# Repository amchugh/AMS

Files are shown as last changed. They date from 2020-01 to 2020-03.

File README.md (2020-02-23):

# AMS - Audio Monitoring System

This system utilizes multiple hardware nodes to listen for sound levels and display an aggregate view on a 
'server' instance.  

Nodes are comprised of:
 * Adafruit Feather Huzzah with ESP8266 - https://www.adafruit.com/product/2821
 * Featherwing OLED displays - https://www.adafruit.com/product/2900
 * Electret microphones - https://www.adafruit.com/product/1063

Server instance is:
 * Adafruit Feather Huzzah with ESP8266 - https://www.adafruit.com/product/2821
 * Featherwing touch screen display - https://www.adafruit.com/product/3315

The goal for fidelity of information being transferred is:
- ~100 samples sent from the listening nodes to the server 
- <=5% drop rate at 30ft through a wall
- Number of packets per second and therefore their size will be determined by packet processing speed on the server. 

## Diagnosing a server instance

It is possible to run the server instance in a 'data gathering' mode.  Compile
and flash the ServerFirmware with DEBUG_PRINT_SHOW_DATA_DETAILS defined at the 
top of the file.  Use the arduino software's serial monitor (or any other
program to see the serial output) making sure that the baud rate matches the
configuration in the server firmware (currently 57600 baud).  

Connect a client or run:

```
python sendExampleSequence.py 1 1 
```

from the commnad line.  The output lines look like this:

```
...
handleUDPPacket; currentTime: 409759, IP: 192.168.4.2, ID: 1, stationIndex: 0, packetNumber: 132, dataIndex: 3, data: 47
handleUDPPacket; currentTime: 409844, IP: 192.168.4.2, ID: 1, stationIndex: 0, packetNumber: 134, dataIndex: 0, data: 93
...
```

The IP, ID and stationIndex are all used to distinguish one listening station
from another.  IP will likely be unique and sufficient.  A single packet can
contain many data values and dataIndex is the index of the data value (the
last component in the log line) within the packet.

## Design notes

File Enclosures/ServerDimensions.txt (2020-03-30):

Dimensions for the Adafruit 2.4inch TFT display for the Featherwing

--

64.77 Wide  (midpoint: 32.385)
52.578 Tall (midpoint: 26.289)

Viewing window 50.75mm x 38.5mm 
It is 7.01 mm from each side
It is 7.04 mm from the top to bottom

--

2.54mm diameter of circles.
The center is offset 2.54mm from the side

4mm from each end.

--

Good thickness/heights are as follows.
For the front panel 2mm thick for the outer wall.
The Post should be 4mm beyond that (6mm high).
The little post should be 3mm beyond that (9mm).

A 2mm round over in the viewing area for the screen.
(Too much and you get some ugly flatness.)

Make the outer wall be 6mm tall. 

--

Assume using 3mm screws to attach the top to the base. 

--

Captive nut for M3 screw is:
  - 5.45mm across the flats 
  - 6.06 across the corners 
  - 3.16 for each side
  - 2.24mm for its depth 

--

Power button is 6.2mm wide.
12.25mm at tallest point.
10.25 at least tallest point.

Opening for the USB cord is:
  12mm wide
  10mm tall
   3mm deep

--

60 degree tilt.
26mm height for the base.

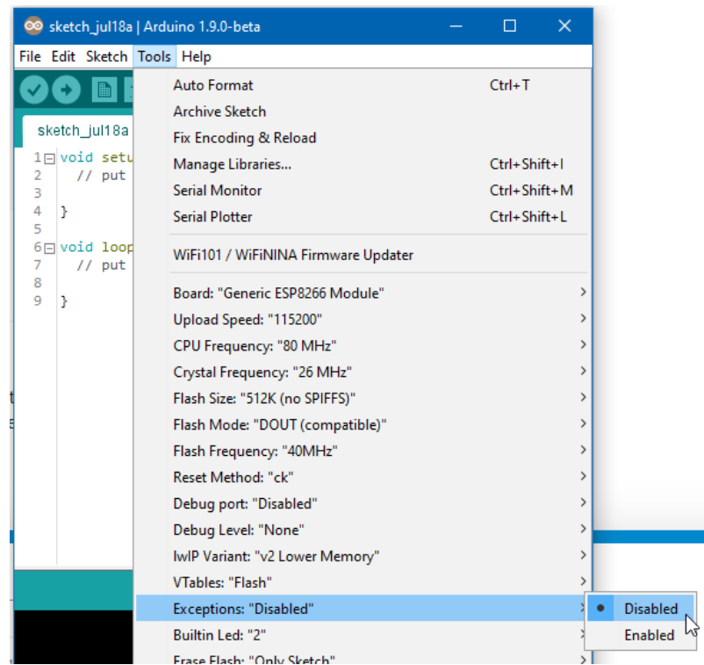
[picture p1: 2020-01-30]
images/MustEnableExceptions.PNG

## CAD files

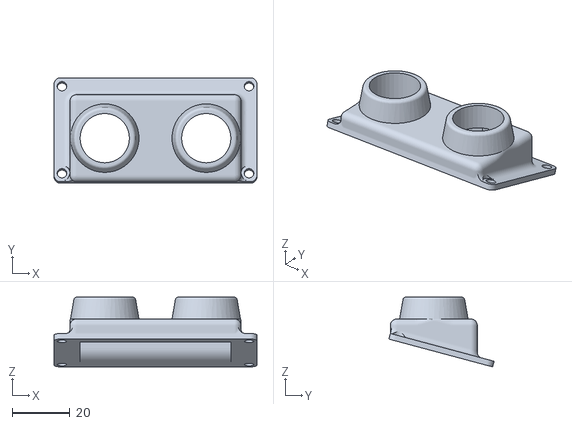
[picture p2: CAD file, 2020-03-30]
Enclosures/us_range.STL
70.0 x 36.3 x 24.1

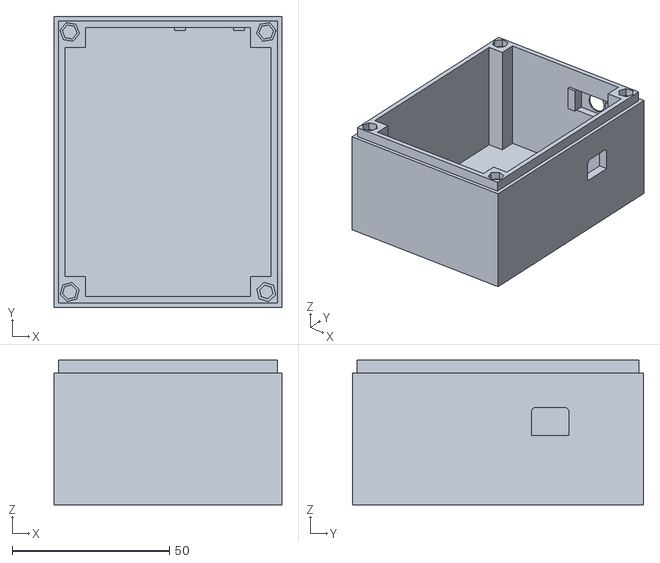
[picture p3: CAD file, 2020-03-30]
Enclosures/S-Bottom-V12.stl
72.6 x 92.8 x 46.0

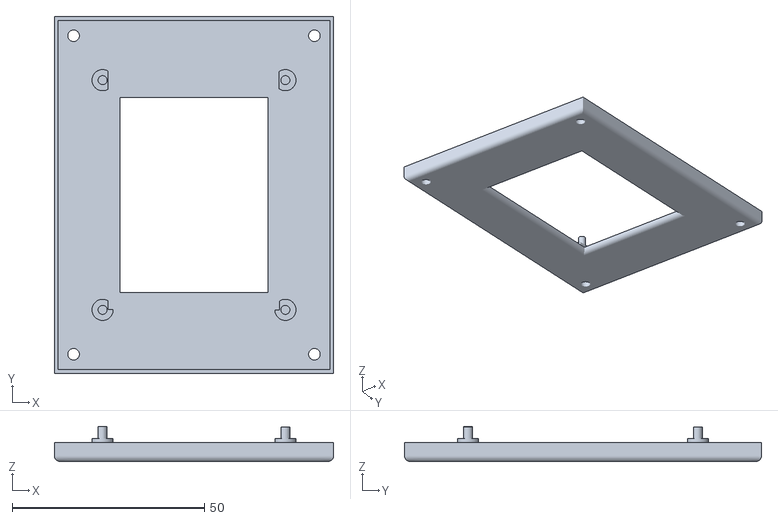
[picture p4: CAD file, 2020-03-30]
Enclosures/S-Top-V12.stl
72.6 x 92.8 x 9.10

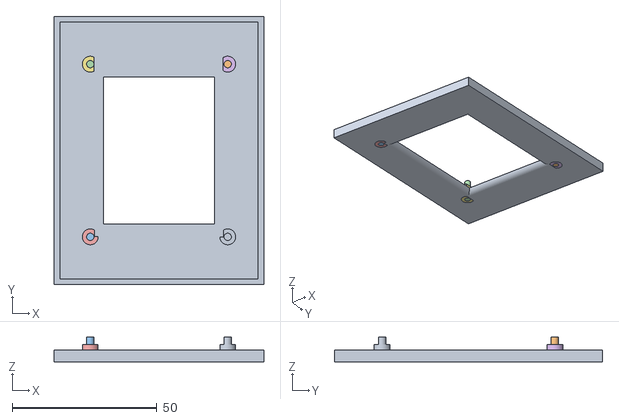
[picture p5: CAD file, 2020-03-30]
Enclosures/S-v2.stl
72.6 x 92.8 x 8.50

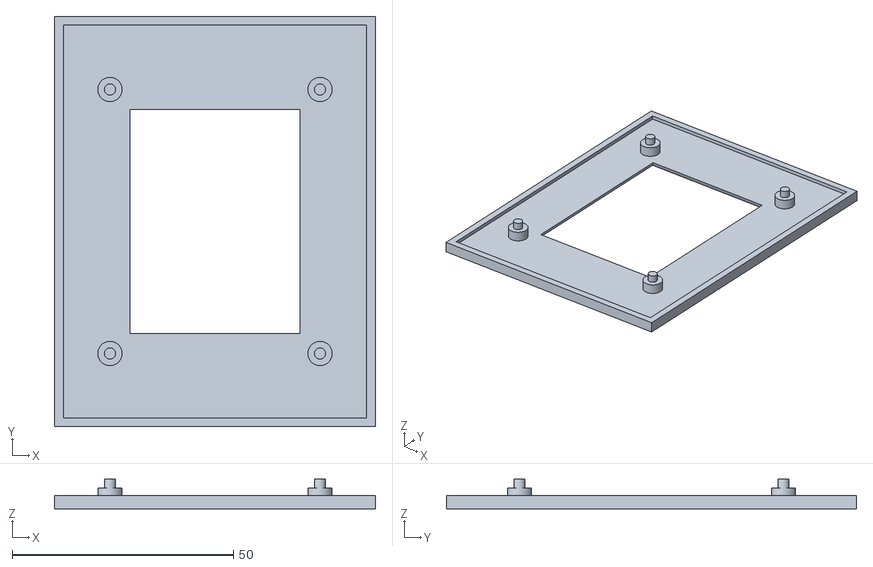
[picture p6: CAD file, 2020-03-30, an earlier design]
Enclosures/S-V1.stl
72.6 x 92.8 x 6.75

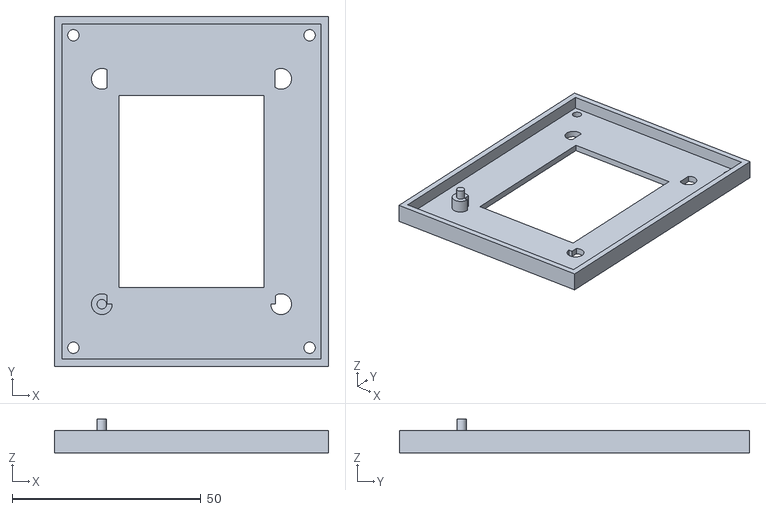
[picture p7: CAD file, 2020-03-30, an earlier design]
Enclosures/S-Top-v3.stl
72.6 x 92.8 x 9.00

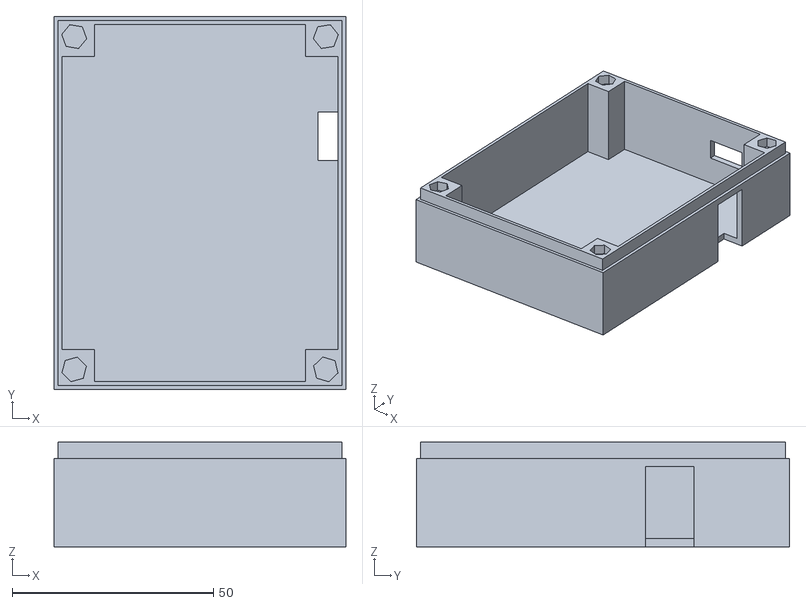
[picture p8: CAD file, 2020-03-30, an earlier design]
Enclosures/S-bottom-v3.stl
72.6 x 92.8 x 26.0

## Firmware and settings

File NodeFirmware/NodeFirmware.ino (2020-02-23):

// This is the listener 'node' code and is intended to be run on an Adafruit
// Feather Huzzah (https://www.adafruit.com/product/2821) coupled with a
// 128x32 OLED FeatherWing display
// (https://learn.adafruit.com/adafruit-oled-featherwing?view=all)
// and an electret microphone (https://www.adafruit.com/product/1063).

// When uploading the code ensure that 
//  Board: Adafruit Feather Huzzah ESP8266
//  Upload speed: 115200
//  CPU: 80 Mhz

// Needed Libraries:
// Adafruit GFX Library - https://github.com/adafruit/Adafruit-GFX-Library
// WiFiManager for ESP8266 by tzapu - https://github.com/tzapu/WiFiManager
// Adafruit_SSD1306 - https://github.com/adafruit/Adafruit_SSD1306

#include <Wire.h>
#include <Adafruit_GFX.h>
#include <Adafruit_SSD1306.h>
#include <ESP8266WiFi.h>
#include <WiFiUdp.h>

// Define server constants
const char *ssidtarget = "AMS-server";

// Location of the server
IPAddress destip(192,168,4,1);
unsigned int serverUDPPort = 8888;

// Setup our listen port
unsigned int localUDPPort = 8888;

// Define the display
Adafruit_SSD1306 display = Adafruit_SSD1306(128, 32, &Wire);

// Define the Udp service!
WiFiUDP Udp;

// Define the button pins
#define A_BUTTON 0
#define B_BUTTON 16
#define C_BUTTON 2

// Define buffers for UDP incoming and outgoing data
char ipacket[UDP_TX_PACKET_MAX_SIZE];
char opacket[UDP_TX_PACKET_MAX_SIZE];

bool doSend = false;
bool wasPressed = false;
uint32_t packetNumber = 0;
uint8_t stationId;
float accumulationSamplesSent = 0;
uint32_t accumulationStartTime = 0;

// The listener node collects data 'samples' and packages them together
// into a 'packet' of data that is communicated with the server.   A 
// single 'sample' is actually many readings of the microphone where we
// are looking in the distance between the high and low value.  
typedef struct {
  uint16_t minValue;
  uint16_t maxValue;
  uint16_t sampleCount;
} Sample;

void setup() {
  Serial.begin(57600);
  // Set the button pinmodes
  pinMode(A_BUTTON, INPUT_PULLUP);
  pinMode(B_BUTTON, INPUT_PULLUP);
  pinMode(C_BUTTON, INPUT_PULLUP);
  // Define the pinmode for the audio sensor
  pinMode(A0, INPUT);

  // Init the display
  display.begin(SSD1306_SWITCHCAPVCC, 0x3c);

  // Try to connect to the server
  WiFi.persistent(false);
  WiFi.mode(WIFI_STA);
  WiFi.begin(ssidtarget, NULL);

  // Print the "searching" message
  int numDots = 0;
  while (WiFi.status() != WL_CONNECTED) {
    if (numDots == 0) { 
      printSearching();
    }
    delay(50);
    Serial.print(".");
    display.print(".");
    display.display();
    numDots++;
    if (numDots == 32) { 
      numDots = 0;
    }
  }
  Serial.println();
  Serial.println("Connected!");

  stationId = WiFi.localIP()[3];

  // Set up the UDP service
  Udp.begin(localUDPPort);

  // Print the ready message
  printConnected();
}

// ------------------------------
// Printing section

// Print a message saying that we are connected to WiFi
void printConnected() {
  display.clearDisplay();
  display.setTextSize(1);
  display.setTextColor(SSD1306_WHITE);
  display.setCursor(0,0);
  display.print("Station ");
  display.print(stationId);
  display.println(" Connected!");
  display.println();
  display.println("Press A to begin");
  display.display();
}

// Print a message to the display that we are searching
void printSearching() {
  display.clearDisplay();
  display.setTextSize(1);
  display.setTextColor(SSD1306_WHITE);
  display.setCursor(0,0);
  display.println("Connecting");
  display.display();
}

void printSendingMessage() {
  display.clearDisplay();
  display.setTextSize(1);
  display.setTextColor(SSD1306_WHITE);
  display.setCursor(0,0);
  display.println("Sending Data");

  display.setCursor(0,16);
  display.println("Packets: ");

  // SPS is 'samples per second'.  This gives us a sense of how many 
  // noise readings per second we are sending.  
  display.setCursor(0,24);
  display.println("SPS: ");

  display.display();
}

void printStandbyMessage(int packetCount) {
  display.clearDisplay();
  display.setTextSize(1);
  display.setTextColor(SSD1306_WHITE);
  display.setCursor(0,0);
  display.println("Standing By");
  display.println("Press A to begin");
  display.print("Packets Sent: ");
  display.println(packetCount);
  display.display();
}

// ------------------------------

void handleUDPPacket() {
 int packetSize = Udp.parsePacket();
 if (packetSize) {
    Serial.printf("Received packet of size %d from %s:%d\n    (to %s:%d, free heap = %d B)\n",
                  packetSize,
                  Udp.remoteIP().toString().c_str(), Udp.remotePort(),
                  Udp.destinationIP().toString().c_str(), Udp.localPort(),
                  ESP.getFreeHeap());

    // read the packet into packetBufffer
    int n = Udp.read(ipacket, UDP_TX_PACKET_MAX_SIZE);
    ipacket[n] = 0;
    Serial.println("Contents:");
    Serial.println(ipacket);
  }
}

// ---------------------------
// Collecting and Sending Data
//
// For details on the packet layout for both the header data and the 
// samples themselves see PacketDecoder.h.  

// The number of bytes allocated for the header data.  
#define HEADER_SIZE_BYTES 2

// How many pieces of sensor information should be in each packet?
// MUST BE A MULTIPLE OF 4 TO ENSURE PROPER ENCODING
const uint16_t PACKETSAMPLESIZE = 16;

// The current index for a data sample within the larger packet. 
uint16_t currentSample = 0;

// Sets the information in the header of the packet
void setupPacket() {
  // Clear out the entire packet so the bit manipulations work correctly.
  memset(opacket, 0, UDP_TX_PACKET_MAX_SIZE);

  currentSample = 0;
  opacket[0] = stationId;
  opacket[1] = packetNumber % (256);
}

// In testing our hardware we can get about 50 samples in a 5 millisecond
// period.  Shorter durations here will make the unit more responsive.
// Keep in mind that we collect many samples before sending them to the
// server.
#define SAMPLE_DURATION_MS 10
Sample getDataSample() { 
  Sample result;

  result.maxValue = 0;
  result.minValue = 1025;
  result.sampleCount = 0;

  unsigned long startMillis = millis();  

  while (millis() - startMillis < SAMPLE_DURATION_MS) {
    uint16_t v = analogRead(A0);
    if (v > result.maxValue) {
      result.maxValue = v; 
    } 
    if (v < result.minValue) {
      result.minValue = v; 
    }
    result.sampleCount++;
  }
  return result;
}

uint8_t getPacketSize() {
  int groupNumber = currentSample / 4;
  return HEADER_SIZE_BYTES + (groupNumber) * 5;
}

// This method will get the data from the sensor and add it to the out packet
void collectData() {

  Sample s = getDataSample();

  // The raw data values are not useful but the difference in the minimum and
  // maximum value gives us a sense of volume level that has occured during
  // the time we have sampled the waveform. 
  uint16_t d = s.maxValue - s.minValue;

#ifdef DEBUG
  Serial.printf("collectData; min: %d, max: %d, count: %d, v: %d\n", 
    s.minValue, s.maxValue, s.sampleCount, d);
#endif

  // The 10 bit value appearing in d is placed in the outgoing packet. 
  // Current encoding puts the first 8 bits in the next available slot
  // then the last 2 bits in with a group of other high order bits.
  int group_number   = currentSample / 4;
  int s_group_pos    = currentSample % 4;
  int group_byte_loc = HEADER_SIZE_BYTES + ((group_number+1) * 5) - 1;   // -1 for index 0
  int s_byte_loc     = HEADER_SIZE_BYTES + (group_number*5 + s_group_pos); 

  opacket[s_byte_loc]     = d & 0xFF;
  opacket[group_byte_loc] = opacket[group_byte_loc] | ((d >> 8) << 2*s_group_pos);

  // Increment counters
  currentSample++;
  accumulationSamplesSent++;
}

// Sends whatever is in the opacket and resets counters
void sendPacket() {
  Udp.beginPacket(destip, serverUDPPort);
  Udp.write(opacket, getPacketSize());
  Udp.endPacket();
}

void loop() {
  if (!digitalRead(A_BUTTON)) {
    // Toggle the behavior when the A button is pressed back and forth between
    // our two modes.
    if (!wasPressed) {
      if (doSend) {
        doSend = false;
        printStandbyMessage(packetNumber);
      } else {
        accumulationStartTime = millis();
        accumulationSamplesSent = 0;
        doSend = true;
        printSendingMessage();
      }
      wasPressed = true;
    }
  } else {
    wasPressed = false;
  }

  if (doSend) {
    // Get ready for the next packet to be sent. 
    setupPacket();

    // We use a tight while loop here so that we accumulate and send an 
    // entire packet of data with semi-strict timing requirements.  
    while (currentSample < PACKETSAMPLESIZE) {
      collectData();
    } 
    sendPacket();
    packetNumber++;
  
    display.fillRect(53,16,70,8, SSD1306_BLACK);
    display.setTextColor(SSD1306_WHITE);
    display.setCursor(53,16);
    display.print(packetNumber);

    unsigned long int elapsedTime = millis() - accumulationStartTime;
    if (elapsedTime > 3000) { 
      // Every so often update the sps - Samples Per Second.
      display.fillRect(53,24,70,8, SSD1306_BLACK);
      display.setTextColor(SSD1306_WHITE);
      display.setCursor(53,24);
      display.print( (float) 
        ( (accumulationSamplesSent) / ( (float)elapsedTime / 1000) ) 
      );

      accumulationStartTime = millis();
      accumulationSamplesSent = 0;
    }
    display.display();
  }

  // See if there are any UDP packets for us to process.
  handleUDPPacket();
}

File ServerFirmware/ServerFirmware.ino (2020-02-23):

// Libraries necessary for this firmware:
//   Adafruit GFX Library - https://github.com/adafruit/Adafruit-GFX-Library
//   Adafruit ILI9341 Library - https://github.com/adafruit/Adafruit_ILI9341
//   Adafruit STMPE610 - https://github.com/adafruit/Adafruit_STMPE610
//   Mini Grafx by Daniel Eichhorn - https://github.com/ThingPulse/minigrafx
//   WiFiManager for ESP8266 by tzapu - https://github.com/tzapu/WiFiManager

// 
// This is the 'server' code and is intended to be run on an Adafruit Feather 
// Huzzah (https://www.adafruit.com/product/2821) coupled with a TFT 
// Featherwing 2.4" touchscreen (https://www.adafruit.com/product/3315).  
// 
// When uploading the code ensure that 
//  Board: Adafruit Feather Huzzah ESP8266
//  Upload speed: 115200
//  CPU: 80 Mhz


#include <SPI.h>
#include <Adafruit_GFX.h>
#include <Adafruit_ILI9341.h>
#include <Adafruit_STMPE610.h>
#include <ESP8266WiFi.h>
#include <ESP8266WebServer.h>
#include <WiFiUdp.h>
#include "Station.h"
#include "PacketDecoder.h"
#include "GfxGraphing.h"
#include "SmartTextField.h"

// Defines used for the TFT display
#define STMPE_CS 16
#define TFT_CS   0
#define TFT_DC   15
#define SD_CS    2


// DEBUG_PRINT* defines will output via the serial interface debug information 
// #define DEBUG_PRINT
// #define DEBUG_PRINT_SHOW_DATA_DETAILS

// Keeping things simple with a maximum number of stations that are tracked with this instance.
#define MAX_NUMBER_STATIONS 4
Station stations[MAX_NUMBER_STATIONS];

const char *ssid = "AMS-server";
unsigned int localUDPPort = 8888;

// Graphical elements
SegmentedBarGraph *g[MAX_NUMBER_STATIONS];
SmartTextField<int> *connTextField;
SmartTextField<int> *packetsTextField;

// Allocate buffers for sending and receiving UDP data.
// The maximum UDP packet size is defined in https://github.com/esp8266/Arduino/blob/master/libraries/ESP8266WiFi/src/WiFiUdp.h
// and, as of 1/22/2020, is 8k.  
byte incomingPacket[UDP_TX_PACKET_MAX_SIZE+1]; 

// An HTTP server exists for diagnostic and debugging purposes
ESP8266WebServer server(80);

WiFiUDP Udp;
Adafruit_ILI9341 tft = Adafruit_ILI9341(TFT_CS, TFT_DC);
Adafruit_STMPE610 ts = Adafruit_STMPE610(STMPE_CS);

// The number of milliseconds to delay between each frame render.
#define RENDER_FRAME_DELAY_MS 30
uint32_t lastGraphRenderTime = 0;

void setup() {
  Serial.begin(57600);

  delay(10);
  Serial.println("Server firmware started.");
  tft.begin();
  tft.setRotation(1);

  // The Wifi library for the ESP8266 tries to be too smart for its own
  // good.  At one point I had flashed another program to the server which 
  // connected to the AP.  This was saved in flash and then it would always
  // even when softAP mode was enabled, try to connect to it.  When it 
  // didn't exist then the AP SSID would go in and out and I was only able
  // to receive 1 of every 4 packets.  Finally tracked it down.  The below
  // makes it explicit that I don't want the 'smarts' found within the 
  // library.
  WiFi.setAutoConnect(false);
  WiFi.persistent(false);
  WiFi.mode(WIFI_AP);

  // Create a soft access point for the stations to connect to.
  bool result = WiFi.softAP(
    ssid,
    NULL,  /* Password - null means none */
    7,     /* Channel number 1 - 13 available.  Default is 1. */
           /* Use a program like WiFi Analyzer to find best channel */
    false, /* Is the SSID hidden? */ 
    5      /* Maximum number of connections */
  ); 
  if (!result) { 
    Serial.println("Unable to setup the softAP mode!");
    tft.fillScreen(ILI9341_BLACK);
    tft.setCursor(0, 0); tft.setTextColor(ILI9341_RED); tft.setTextSize(2);
    tft.println("Error creating soft AP");
    delay(5000);
    while(1) {}
  }

  displayWelcome();

  // Start listening for packets on the UDP port.
  Udp.begin(localUDPPort);
    
  server.on("/", handleRoot);
  server.begin();
  Serial.println("HTTP server started");

#define XOFFSET 40 
#define WIDTH 320

#define SEGMENTSIZE ((WIDTH - (XOFFSET*2)) / MAX_NUMBER_STATIONS)

  //  0     40    100    160    220    280     320
  //  |     |      +      +      +       |      |

  for (int i=0; i<MAX_NUMBER_STATIONS; i++) { 
    initializeStation(stations[i]);
    g[i] = new SegmentedBarGraph( tft, XOFFSET + (SEGMENTSIZE * i) + ((SEGMENTSIZE - 2*24)/2), 32, 24, 152 );
    g[i]->setBackgroundColor(ILI9341_BLACK);
    g[i]->setBorderColor(ILI9341_WHITE);
    g[i]->setMinAndMaxYAxisValues(0, 1024);
    g[i]->setSegmentGroupColors(ILI9341_GREEN, ILI9341_YELLOW, ILI9341_RED);
    g[i]->startGraphing();
  }
  for (int i=0; i<(MAX_NUMBER_STATIONS-1); i++) { 
    tft.drawFastVLine(XOFFSET + (SEGMENTSIZE * i) + 46, 22, 210, ILI9341_RED);
  }
}

void handleRoot() {
  server.send(200, "text/html", "<h1>You are connected</h1>");
}

void displayWelcome() {
  tft.fillScreen(ILI9341_BLACK);
  tft.setCursor(0, 0); tft.setTextColor(ILI9341_RED); tft.setTextSize(2);
  tft.println("AMS Server");

  tft.setCursor(150,4);
  tft.setTextColor(ILI9341_WHITE); tft.setTextSize(1);
  tft.println( "Conns: 0");
  tft.setCursor(220,4);
  tft.println( "Packets: 0");

  connTextField = new SmartTextField<int>(tft, 191, 4, 24, 8, ILI9341_BLACK);
  packetsTextField = new SmartTextField<int>(tft, 274, 4, 64, 8, ILI9341_BLACK);
}

int numberOfPacketsReceived = 0;
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

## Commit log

2020-01-23 Create NodeFirmware.ino
    Initial commit of Node Firmware as I'm burnt out of creative writing
    [NodeFirmware.ino]
2020-01-24 Fixed and working UDP traffic
    This version fixes a bug where both the node and the server were in AP mode.
    The node now sets itself up properly to connection as a STA to the server AP.
    Also added some basic diagnostic output to the screens used in both.
    [NodeFirmware.ino, ServerFirmware.ino]
2020-01-24 More efficient update and first pass on Station data model
    I've removed the delays in the prior server instance since we
    may have been seeing some packetloss and delays due to that.
    Also more efficient updates of the screen with bounding boxes
    that are tight around the information that is being changed.
    Added a first pass on the station data model.
    [ServerFirmware.ino]
2020-01-28 Updated Station Firmware
    Station firmware sends 8 samples per packet and sends them as fast as it can. It does no processing of the data. It sends packets with compressed data that needs to be decoded on the other end.
2020-01-29 Decoder hooked into server
    The server instance now uses the decoding logic in order to handle the
    data packet being sent.
    In addition I've altered our sample program 'sendExamplePacket.py' in
    order to encode the data in the expected format. This program now
    allows up to 4 data points to be specified at the command line.
    Calling pattern looks like this:
    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
2020-01-30 First pass on showing results
    After talking with Aidan and discussing the use cases I've created this class that shows a descritized view of the data. This view current draws from the top to the bottom and in a single color but c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
    Documentation and better code is forthcoming.
2020-02-10 Display all stations, shorter highwater mark
    4 changes:
    1/ New UI with all the stations being shown
    2/ Created a test directory and moved current test tools into the directory.
    3/ Iterated on the invalid packet a tiny amount. Added invalid packet counts.
    4/ Shortened the high water mark period so that it is more reactive and doesn't just hang out for 10 seconds!
    TODO:
    1/ Iterate on the display some more and show some information about the age of the station, invalid packet count, number of seconds since seen data.
    2/ Augment the http server with a way to define the range of the values dynamically.
    [ServerFirmware.ino]
2020-02-13 Sample the audio sensor for the waveform
    In this change I've made the node software look at the sensor across a range of
    time (currently 5 milliseconds) and extract from that the min, max and sample count sizes. The difference in raw min and max values gives us the magnitude of the relative waveform and thus a sense of the loudness of the noise within the environment.
    [NodeFirmware.ino]
2020-02-13 Bug fixes and diagnostic data
    Lots of little bug fixes and minor improvements.
    [ServerFirmware.ino]
2020-02-13 Fix packet sizes
    Passing correct packetsizes to write is necessary so that the UDP library knows how many bytes to send. Otherwise it will infer based on the contents.
    [NodeFirmware.ino]
2020-02-22 Better Stats
    Fixed the 'SPS' or 'Samples per second' state that is shown on the screen.
    [NodeFirmware.ino]
2020-02-23 Working with great performance
    Quite a few things in this diff.
    1/ A SmartTextField that simplifies GUI code. This will be especially useful when I add in additional information for each Station.
    2/ I found and fixed an awful performance problem within the Server. It manifested itself by dropping 66% of all packets. Also the SSID wasn't being reliably broadcast. This was due to the ESP8266 Wifi library which tries to do *way* too much. At one point I had flashed to the server unit code which contained an SSID and Password. This was recorded in EEPROM. From this point forward this will attempt to be used unless you explicitly say 'JUST AP' mode. If you don't do this - and just se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
    [NodeFirmware.ino, ServerFirmware.ino]
2020-02-23 Cleanup and documentation
    Some cleaning up of old files and documentation. Also added a bit more explanation
    to the code and fixed a typo from prior commit.
    [NodeFirmware.ino]
2020-02-24 V0.1 of the enclosure
    Just getting started with the enclosure that I would like to create
    for the server instance. Specifications are:
    - Fits a 6,600mAh battery (this is because the station instances will use one really)
    - Fits the overall dimensions of the 2.4" TFT display
    - Allows access to the USB programming mechanism.
2020-02-25 First version of the enclosures
    [S-V1.stl]
2020-02-27 More work on the enclosure
    [S-Top-v3.stl, S-bottom-v3.stl, S-v2.stl]
2020-03-06 Latest iterations on enclosure
    Nearly perfect. Only think I would do is make the button hole just a tiny bit larger and fix the indentation that exists near the usb hole.
    [S-Bottom-V12.stl, S-Top-V12.stl, us_range.STL]
2020-03-06 Perfect, perfect
    Perfect server enclosure when printed at medium or high speed on PLA per Cura's normal configuration.
2020-03-12 Update gitignore
    Temporary files are common within the Enclosures directory to track intermediate forms.
2020-03-30 Disable pin; Better waveform
